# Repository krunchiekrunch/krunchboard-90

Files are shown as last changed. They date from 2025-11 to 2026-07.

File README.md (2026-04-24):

# krunchboard-90
A custom 75% (84+5+1) ANSI mechanical keyboard powered by a Raspberry Pi Pico with KMK

# About
This keyboard has 84 regular keys, 5 programmable macro keys, and 1 switch within the rotary encoder.

## Special Keys

Media Controls:

- Double tap F1: Previous media

- Double tap F2: Pause media

- Double tap F3: Next media

Rotary encoder:

- Turn: Volume Up/Down

- Press/Fn and turn: Brightness Up/Down

- Double press: Mute

[KLE](https://www.keyboard-layout-editor.com/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'&_a:6&w:2.25%3B&=Enter&=Page%20Down&_a:7%3B&=%3B&@_a:6&w:2.25%3B&=Shift&_a:4%3B&=Z&=X&=C&=V&=B&=N&=M&=%3C%0A,&=%3E%0A.&=%3F%0A%2F%2F&_a:6&w:1.75%3B&=Shift&_a:7%3B&=%E2%86%91&_a:6%3B&=End&_a:7%3B&=%3B&@_a:6&w:1.25%3B&=Ctrl&_w:1.25%3B&=Win&_w:1.25%3B&=Alt&_a:7&w:6.25%3B&=&_a:6%3B&=Alt&=Fn&=Ctrl&_a:7%3B&=%E2%86%90&=%E2%86%93&=%E2%86%92&=)

# Images

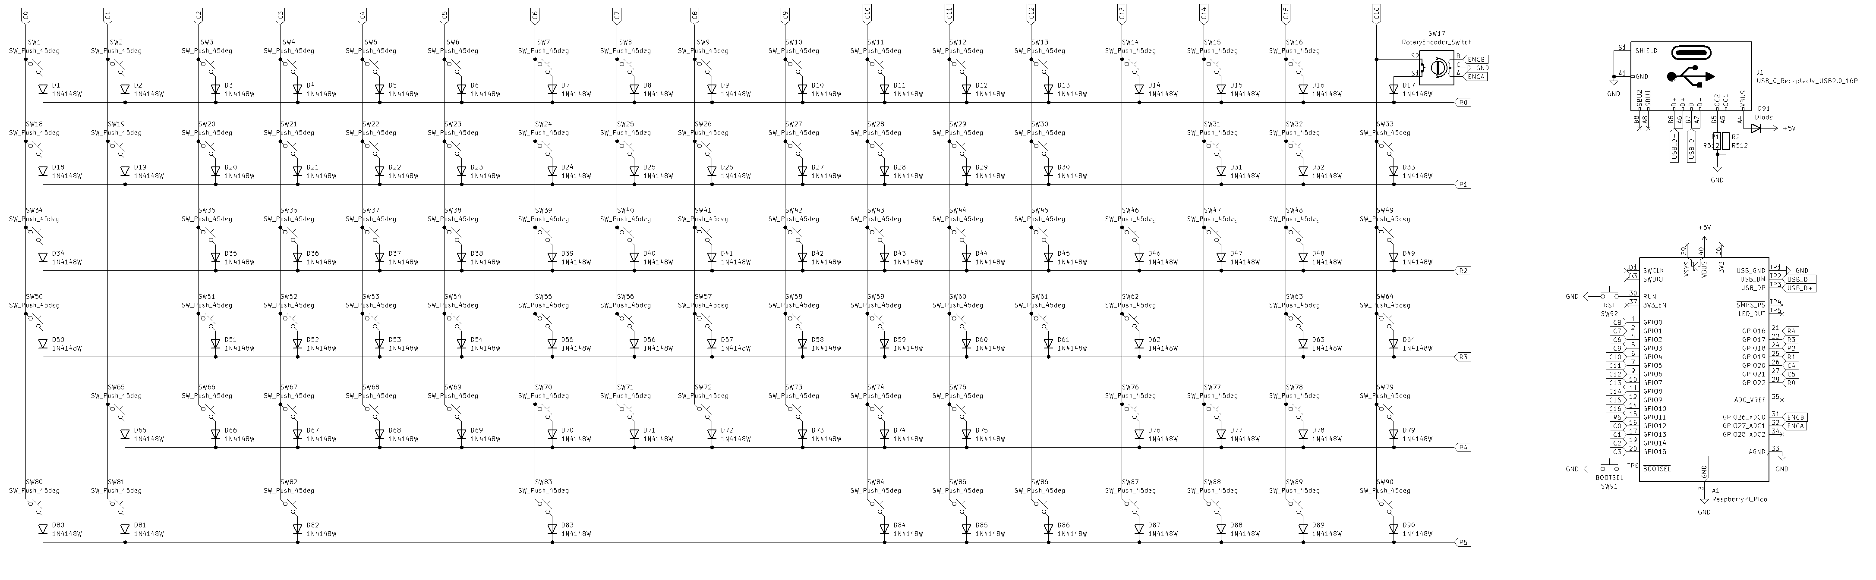
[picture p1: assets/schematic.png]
Schematic


| PCB | 3D View |
|---|---|
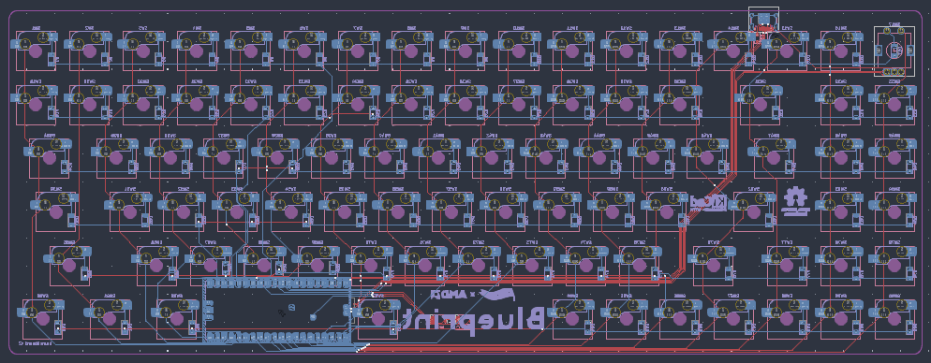
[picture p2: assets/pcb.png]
PCB
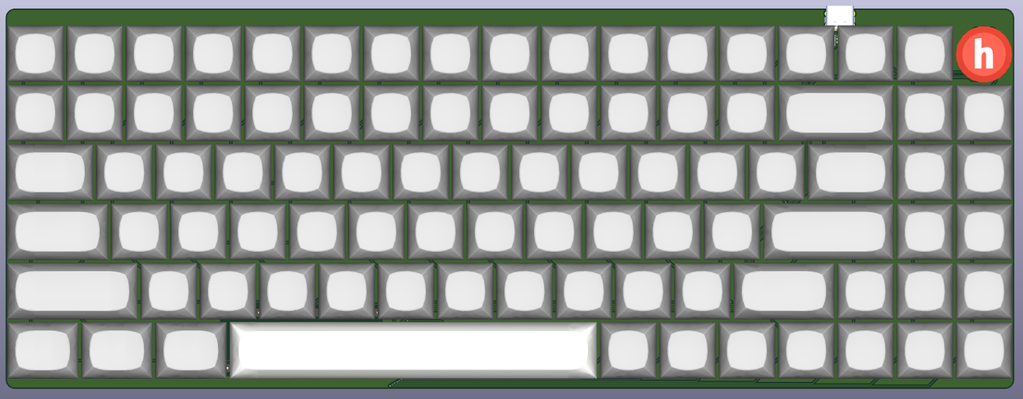
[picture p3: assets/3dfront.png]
3D-Front
|  |  |
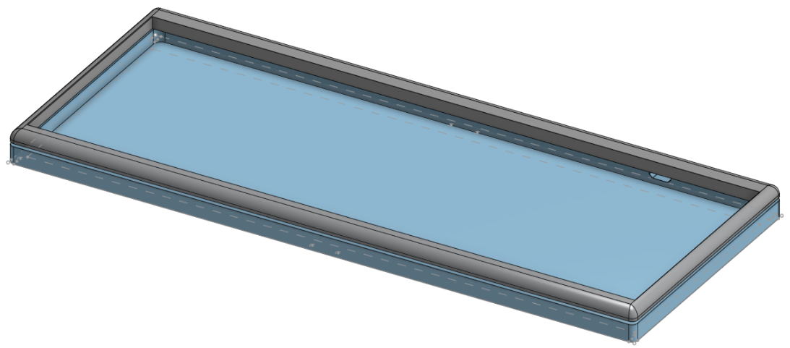
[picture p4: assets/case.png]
Case
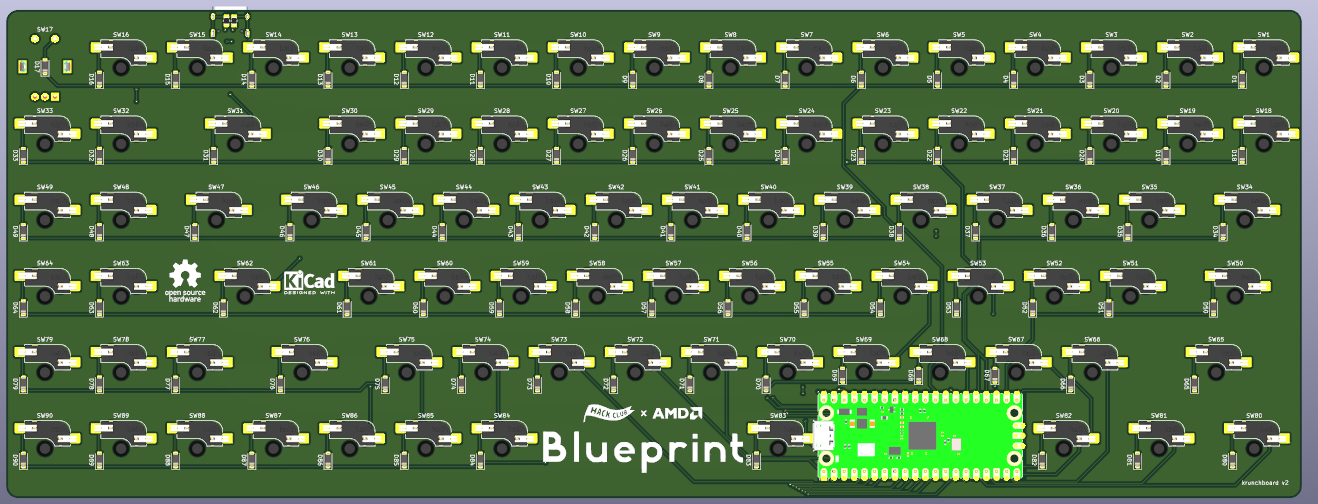
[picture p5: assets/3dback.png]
3D-Back
|  |  | 

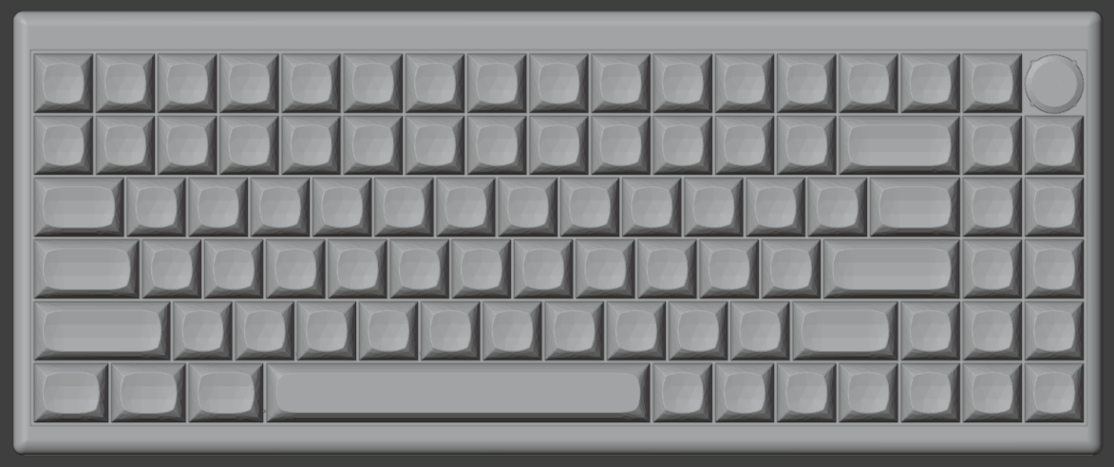
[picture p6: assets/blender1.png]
Blender


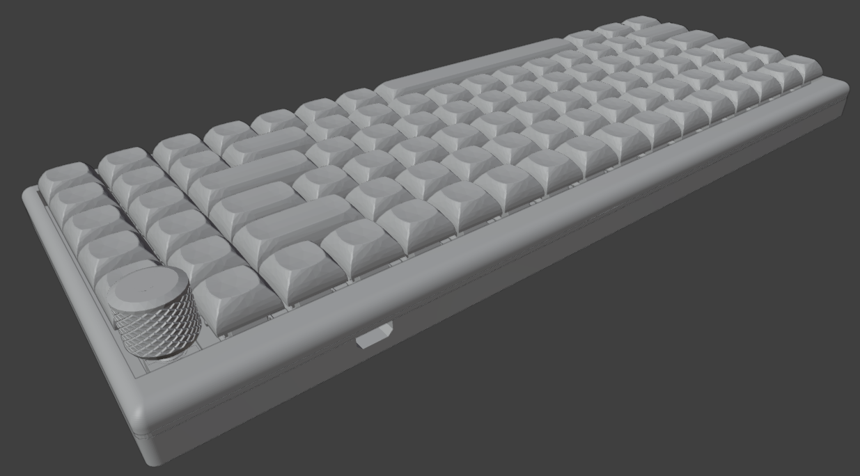
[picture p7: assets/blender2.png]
Blender






# BOM

| Qty | Item | Notes | Cost (USD) | URL |
|-----|---|---|---|-----|
| 89  | MX-Style key switches | Already have | 9.90 | [AE](https://www.aliexpress.com/item/1005002378701948.html) |
| 89  | Kailh MX hotswap socket | Already have | 8.11 | [AE](https://www.aliexpress.com/item/1005007052649640.html) |
| 90  | 1N4148W SOD-123 Diode | Already have | 2.32 | [AE](https://www.aliexpress.com/item/1005009063199018.html) |
| 1 | EC11E Rotary encoder (With switch) | Already have | 2.42 | [AE](https://www.aliexpress.com/item/1005008413622715.html) |
| 3 | MX Stabilizer (3x2u, 1x6.25u) | Already have | 2.42 | [AE](https://www.aliexpress.com/item/1005007212869086.html) |
| 1 | ANSI Keycaps set | Already have | 7.00 | [AE](https://www.aliexpress.com/item/1005007321700850.html) |
| 1 | Raspbery Pi Pico (RP2040 or RP2350) | Already have | 2.30 | [AE](https://www.aliexpress.com/item/1005006054409042.html) |
| 1 | USB-C Socket (SMD) | Already have | 1.00 | N/A |
| 2 | 5.1k/4.7k 0805 SMD resistor | Already have | 1.00 | N/A |
| 4 | M2 Screw (13.9mm max, I used 12mm) | Already have | 1.42 | [AE](https://www.aliexpress.com/item/1005003670389142.html) |
| 4 | M2 Heatset Insert (OD3.2mm, 3mm deep) | Already have | 1.73 | [AE](https://www.aliexpress.com/item/1005007640664497.html) |
| 6 | Stick-on rubber feet (Optional) | Already have | 1.18 | [AE](https://www.aliexpress.com/item/1005006832476105.html) |
| 1 | PCB | (Shipping/Tax included + $20 coupon) | 15.58 | [JLCPCB](https://jlcpcb.com) |
| 1 | 3D Printed case and plate (Blueprint only) | print-legion | 4.65 | N/A |
| | | Total: | 56.38 [20.23] | |



blueprint_logo_centered

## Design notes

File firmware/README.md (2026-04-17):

## Core Setup

* **Board:** Raspberry Pi Pico
* **Firmware:** KMK
* **Matrix:**

  * Rows: `GP22, GP19, GP18, GP17, GP16, GP11`
  * Columns: `GP12 → GP10`
* **Diode Orientation:** `COL2ROW`

## Modules

* **Macros** – custom key sequences
* **MouseKeys** – cursor + mouse control
* **MediaKeys** – volume/media shortcuts
* **EncoderHandler** – rotary encoder support
* **Layers** – multi-layer keymap
* **TapDance** – dual-function tap/hold keys

## Special Features

### Layers

* **Layer 0 (Base)** – standard keyboard layout
* **Layer 1 (Fn)** – mouse controls, system keys, macros

## Mouse Keys (Fn Layer)

  * Cursor movement
  * Left click
  * Right click
  * Scroll up/down

## Rotary Encoder

* **Default layer:**

  * Turn left → Volume Down
  * Turn right → Volume Up
* **Fn layer:**

  * Turn left → Brightness Down
  * Turn right → Brightness Up

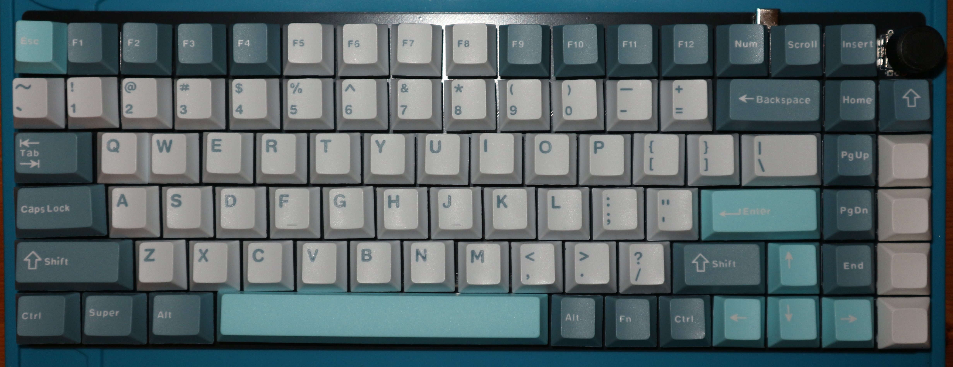
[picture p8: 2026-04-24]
assets/assm-front.JPG

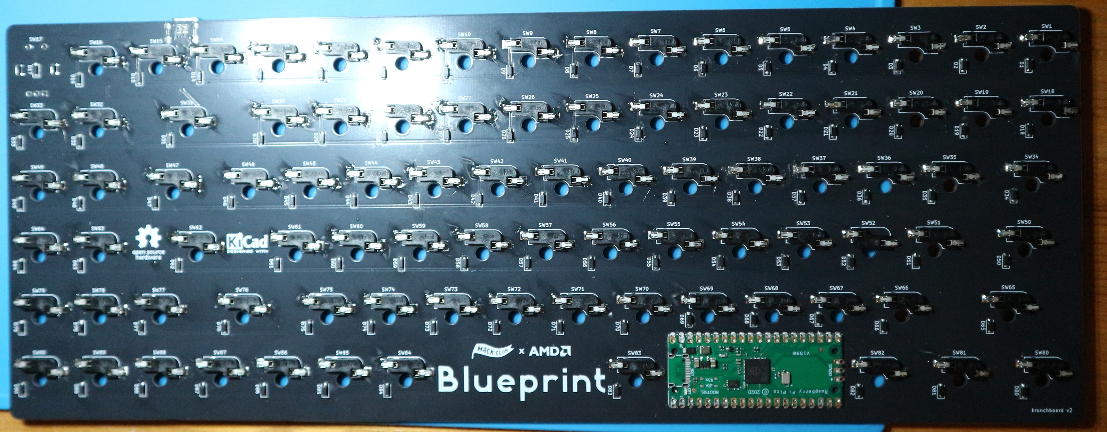
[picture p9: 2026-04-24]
assets/assm-rear.JPG

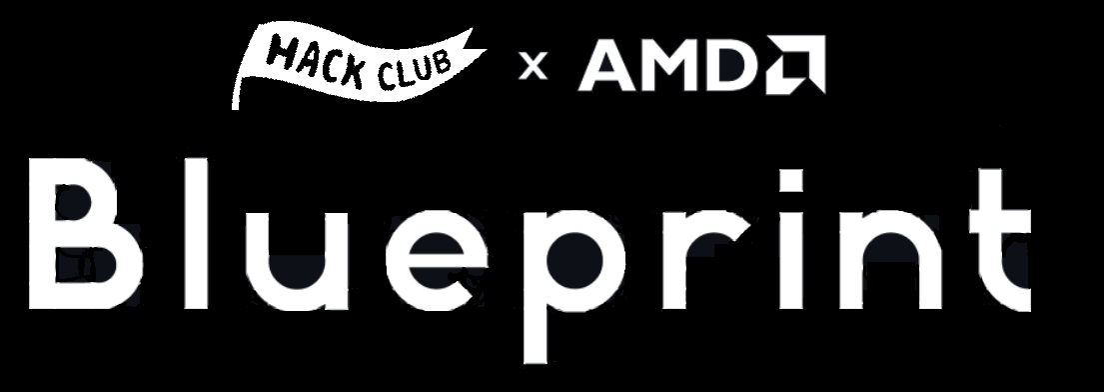
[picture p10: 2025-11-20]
assets/blueprint-monochrome.png

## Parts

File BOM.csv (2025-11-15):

Qty | Item | Notes | Cost (USD) | URL
89 | MX-Style key switches | Already have | 0.00 | N/A
89 | Kailh MX hotswap socket | Already have | 0.00 | N/A
90 | 1N4148W SOD-123 Diode | Already have | 0.00 | N/A
1 | EC11E Rotary encoder (With switch) | Already have | 0.00 | N/A
3 | 2u MX Stabilizer | Already have | 0.00 | N/A
1 | 6.25u MX Stabilizer | Already have | 0.00 | N/A
1 | Keycaps set | Already have | 0.00 | N/A
1 | Raspbery Pi Pico (RP2040 or RP2350) | Already have | 0.00 | N/A
1 | USB-C Socket (SMD) | Already have | 0.00 | N/A
2 | 5.1k 0402 SMD resistor | Already have | 0.00 | N/A
4 | M2 Screw (13.9mm max) | Already have | 0.00 | N/A
4 | M2 Heatset Insert (OD3.2mm, 3mm deep) | Already have | 0.00 | N/A
6 | Stick-on rubber feet (Optional) | Already have | 0.00 | N/A
1 | PCB | (Shipping included + $20 coupon) | 12.01 | https://jlcpcb.com
1 | 3D Printed case and plate | print-legion | 4.60 | N/A
 | Total |  | 16.61

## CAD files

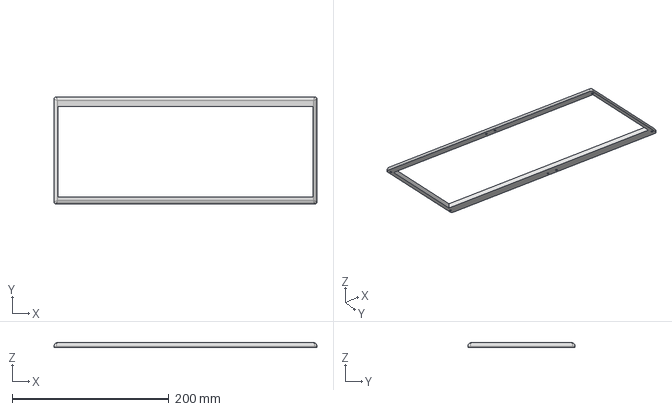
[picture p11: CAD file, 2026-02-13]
case-cad/krunchboard-90-castop.step
335.1 x 136.5 x 6.30 mm

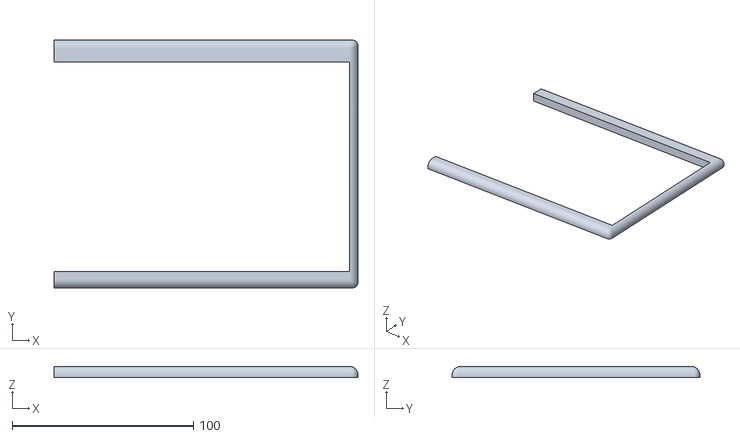
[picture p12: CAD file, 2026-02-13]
production/case-half/krunchboard-90-castop-right.stl
167.5 x 136.5 x 6.30

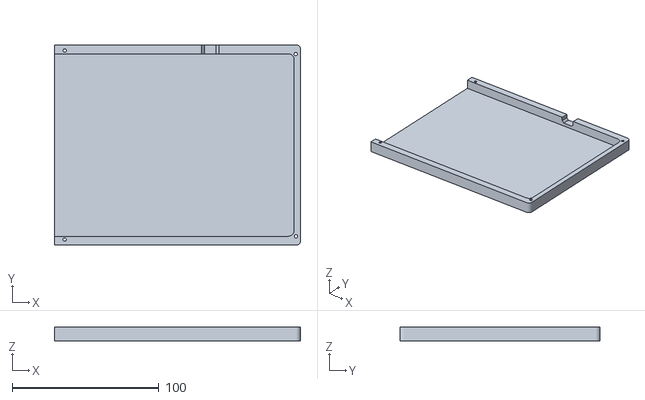
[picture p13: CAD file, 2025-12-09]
production/case-half/krunchboard-90-casebottom-right.stl
167.5 x 136.5 x 9.30

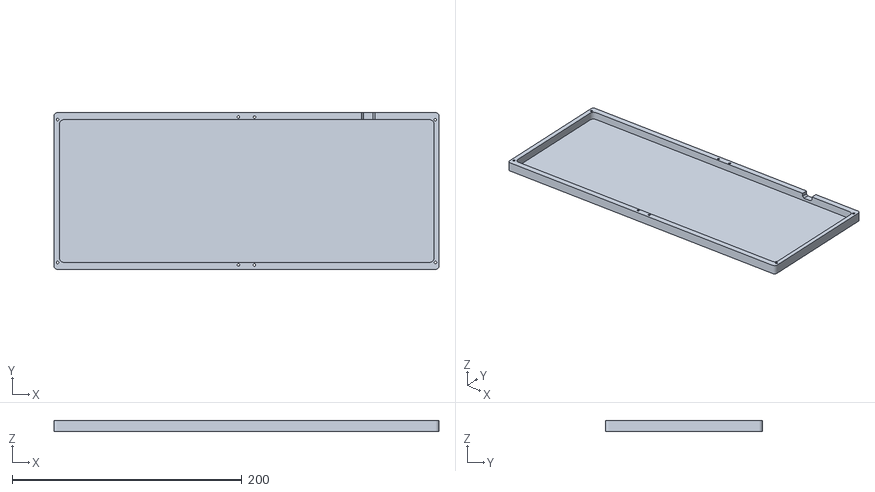
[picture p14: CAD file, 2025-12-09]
production/krunchboard-90-casebottom.stl
335.1 x 136.5 x 9.30

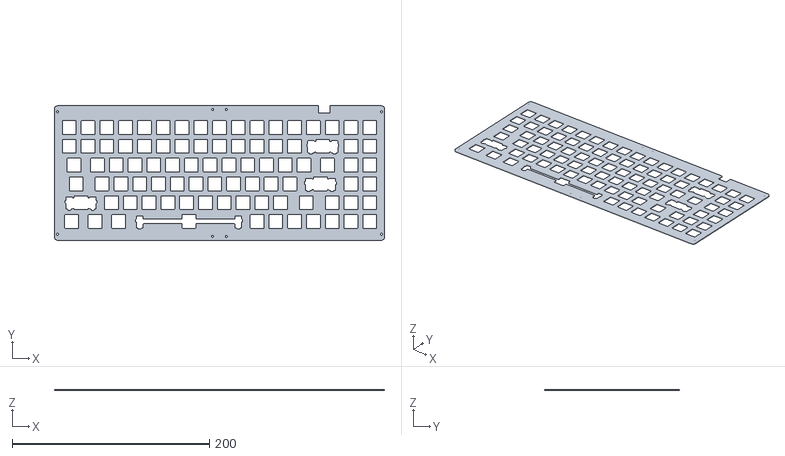
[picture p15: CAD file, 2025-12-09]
production/krunchboard-90-plate.stl
334.8 x 136.5 x 1.51

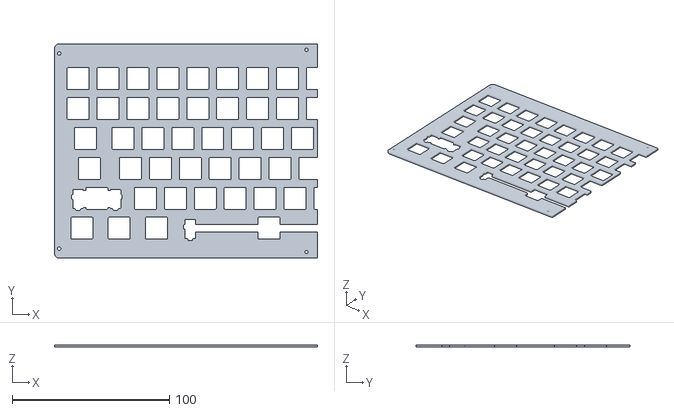
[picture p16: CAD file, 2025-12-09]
production/case-half/krunchboard-90-plate-left.stl
167.4 x 136.5 x 1.51

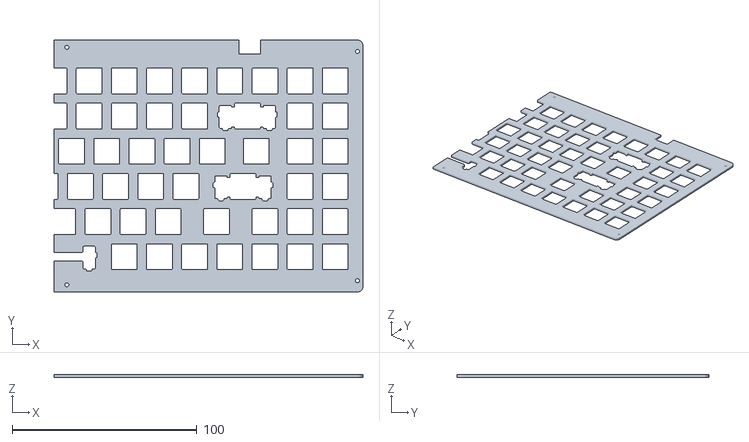
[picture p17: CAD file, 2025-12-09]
production/case-half/krunchboard-90-plate-right.stl
167.4 x 136.5 x 1.51

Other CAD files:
production/krunchboard-90-castop.stl
case-cad/krunchboard-90-casetop.step
case-cad/krunchboard-90-casebottom.step
production/case-half/krunchboard-90-casetop-left.stl
production/case-half/krunchboard-90-casebottom-left.stl
case-cad/krunchboard90-casebottom.step
case-cad/krunchboard90-casetop.step

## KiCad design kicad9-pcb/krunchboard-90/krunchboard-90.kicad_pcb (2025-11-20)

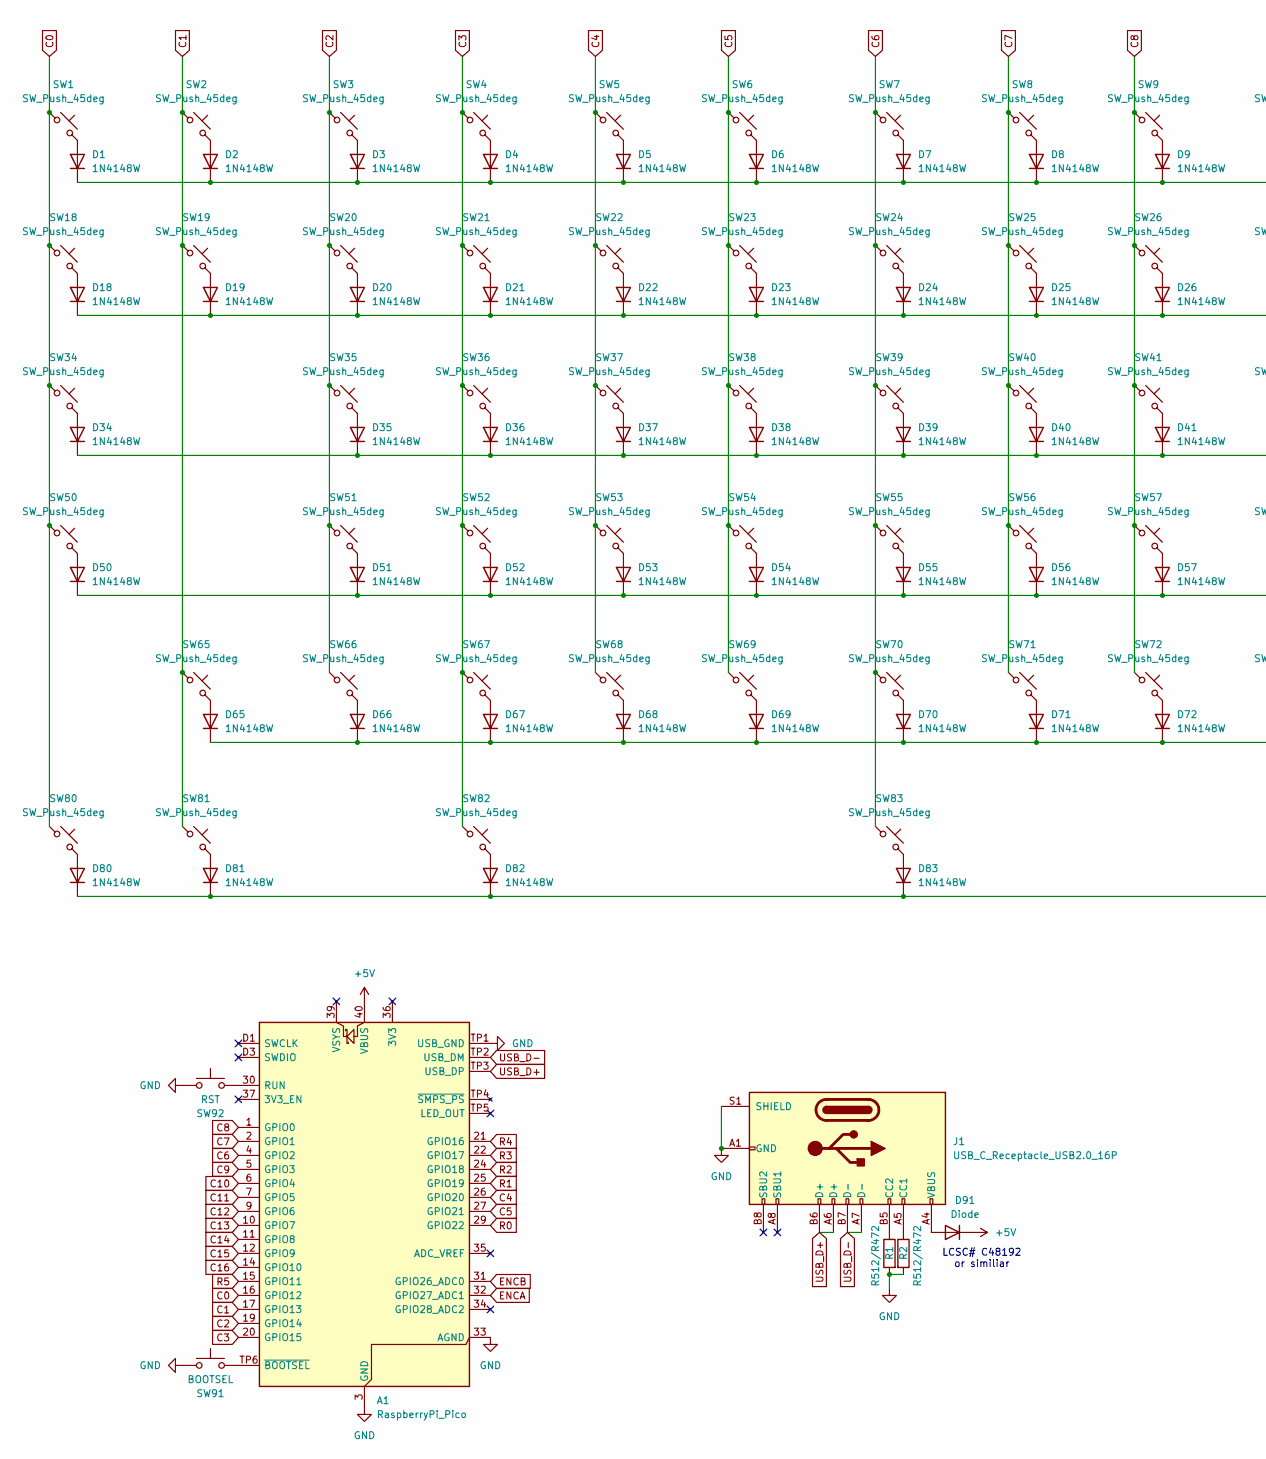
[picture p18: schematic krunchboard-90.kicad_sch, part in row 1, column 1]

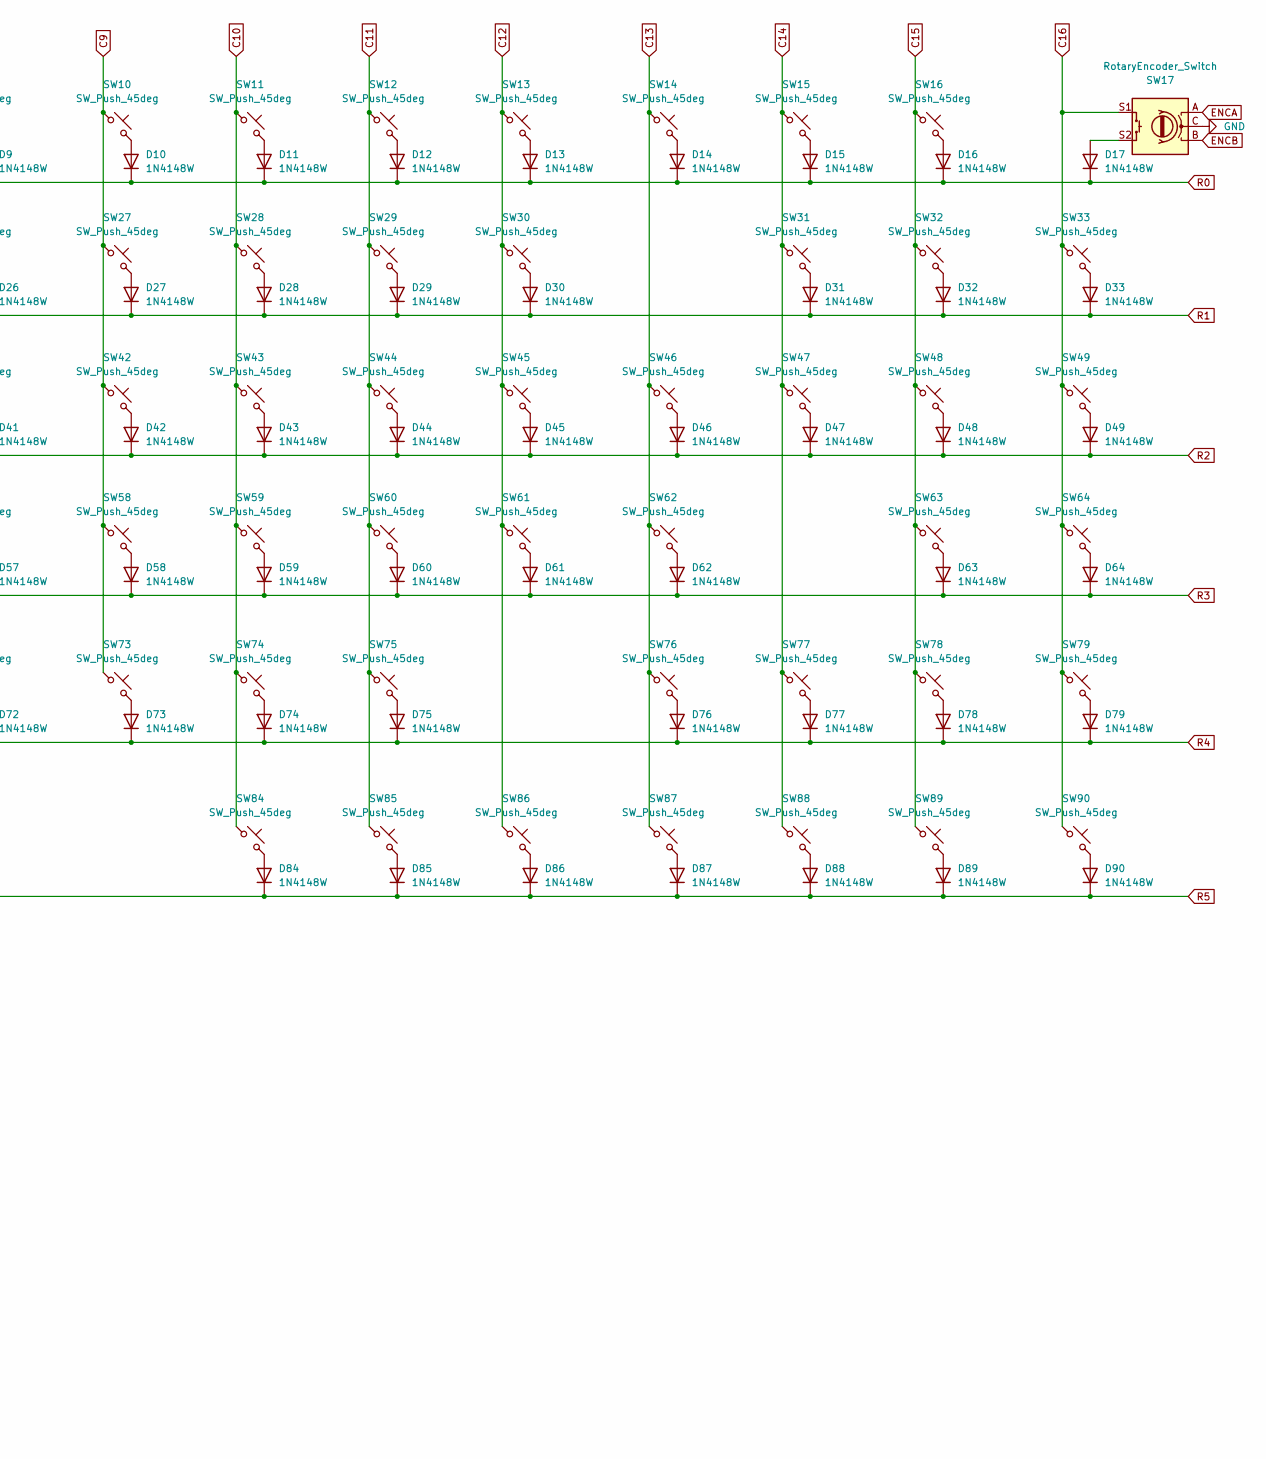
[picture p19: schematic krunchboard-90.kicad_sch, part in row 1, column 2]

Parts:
A1: RaspberryPi_Pico; RaspberryPi_Pico_SMD
D1, D2, D3, D4, D5, D6, D7, D8, D9, D10, D11, D12, D13, D14, D15, D16, D17, D18, D19, D20, D21, D22, D23, D24, D25, D26, D27, D28, D29, D30, D31, D32, D33, D34, D35, D36, D37, D38, D39, D40, D41, D42, D43, D44, D45, D46, D47, D48, D49, D50, D51, D52, D53, D54, D55, D56, D57, D58, D59, D60, D61, D62, D63, D64, D65, D66, D67, D68, D69, D70, D71, D72, D73, D74, D75, D76, D77, D78, D79, D80, D81, D82, D83, D84, D85, D86, D87, D88, D89, D90: 1N4148W; D_SOD-123
D91: Diode; D_SOD-323_HandSoldering
J1: USB_C_Receptacle_USB2.0_16P; USB_C_Receptacle_HCTL_HC-TYPE-C-16P-01A
R1, R2: R512/R472; R_0805_2012Metric_Pad1.20x1.40mm_HandSolder
SW1, SW2, SW3, SW4, SW5, SW6, SW7, SW8, SW9, SW10, SW11, SW12, SW13, SW14, SW15, SW16, SW18, SW19, SW20, SW21, SW22, SW23, SW24, SW25, SW26, SW27, SW28, SW29, SW30, SW31, SW32, SW33, SW34, SW35, SW36, SW37, SW38, SW39, SW40, SW41, SW42, SW43, SW44, SW45, SW46, SW47, SW48, SW49, SW50, SW51, SW52, SW53, SW54, SW55, SW56, SW57, SW58, SW59, SW60, SW61, SW62, SW63, SW64, SW65, SW66, SW67, SW68, SW69, SW70, SW71, SW72, SW73, SW74, SW75, SW76, SW77, SW78, SW79, SW80, SW81, SW82, SW83, SW84, SW85, SW86, SW87, SW88, SW89, SW90: SW_Push_45deg; Kailh_socket_MX_platemount_plated
SW17: RotaryEncoder_Switch; RotaryEncoder_Alps_EC11E-Switch_Vertical_H20mm
SW91: BOOTSEL; SW_SPST_TS-1088-xR025
SW92: RST; SW_SPST_TS-1088-xR025

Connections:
+5V: A1.40 (VBUS), D91.1 (K)
C0: A1.16 (GPIO12), SW1.1, SW18.1, SW34.1, SW50.1, SW80.1
C1: A1.17 (GPIO13), SW2.1, SW19.1, SW65.1, SW81.1
C2: A1.19 (GPIO14), SW3.1, SW20.1, SW35.1, SW51.1, SW66.1
C3: A1.20 (GPIO15), SW4.1, SW21.1, SW36.1, SW52.1, SW67.1, SW82.1
C4: A1.26 (GPIO20), SW5.1, SW22.1, SW37.1, SW53.1, SW68.1
C5: A1.27 (GPIO21), SW6.1, SW23.1, SW38.1, SW54.1, SW69.1
C6: A1.4 (GPIO2), SW7.1, SW24.1, SW39.1, SW55.1, SW70.1, SW83.1
C7: A1.2 (GPIO1), SW8.1, SW25.1, SW40.1, SW56.1, SW71.1
C8: A1.1 (GPIO0), SW9.1, SW26.1, SW41.1, SW57.1, SW72.1
C9: A1.5 (GPIO3), SW10.1, SW27.1, SW42.1, SW58.1, SW73.1
C10: A1.6 (GPIO4), SW11.1, SW28.1, SW43.1, SW59.1, SW74.1, SW84.1
C11: A1.7 (GPIO5), SW12.1, SW29.1, SW44.1, SW60.1, SW75.1, SW85.1
C12: A1.9 (GPIO6), SW13.1, SW30.1, SW45.1, SW61.1, SW86.1
C13: A1.10 (GPIO7), SW14.1, SW46.1, SW62.1, SW76.1, SW87.1
C14: A1.11 (GPIO8), SW15.1, SW31.1, SW47.1, SW77.1, SW88.1
C15: A1.12 (GPIO9), SW16.1, SW32.1, SW48.1, SW63.1, SW78.1, SW89.1
C16: A1.14 (GPIO10), SW17.S1, SW33.1, SW49.1, SW64.1, SW79.1, SW90.1
ENCA: A1.32 (GPIO27_ADC1), SW17.A
ENCB: A1.31 (GPIO26_ADC0), SW17.B
GND: A1.3 (GND), A1.8 (GND), A1.13 (GND), A1.18 (GND), A1.23 (GND), A1.28 (GND), A1.33 (AGND), A1.38 (GND), A1.D2 (GND), A1.TP1 (USB_GND), J1.A1 (GND), J1.A12 (GND), J1.B1 (GND), J1.B12 (GND), J1.S1 (SHIELD), R1.2, R2.2, SW17.C, SW91.1, SW92.1
unnamed: A1.30 (RUN), SW92.2
unnamed: A1.TP6 (~BOOTSEL), SW91.2
unnamed: D1.2 (A), SW1.2
unnamed: D2.2 (A), SW2.2
unnamed: D3.2 (A), SW3.2
unnamed: D4.2 (A), SW4.2
unnamed: D5.2 (A), SW5.2
unnamed: D6.2 (A), SW6.2
unnamed: D7.2 (A), SW7.2
unnamed: D8.2 (A), SW8.2
unnamed: D9.2 (A), SW9.2
unnamed: D10.2 (A), SW10.2
unnamed: D11.2 (A), SW11.2
unnamed: D12.2 (A), SW12.2
unnamed: D13.2 (A), SW13.2
unnamed: D14.2 (A), SW14.2
unnamed: D15.2 (A), SW15.2
unnamed: D16.2 (A), SW16.2
unnamed: D17.2 (A), SW17.S2
unnamed: D18.2 (A), SW18.2
unnamed: D19.2 (A), SW19.2
unnamed: D20.2 (A), SW20.2
unnamed: D21.2 (A), SW21.2
unnamed: D22.2 (A), SW22.2
unnamed: D23.2 (A), SW23.2
unnamed: D24.2 (A), SW24.2
unnamed: D25.2 (A), SW25.2
unnamed: D26.2 (A), SW26.2
unnamed: D27.2 (A), SW27.2
unnamed: D28.2 (A), SW28.2
unnamed: D29.2 (A), SW29.2
unnamed: D30.2 (A), SW30.2
unnamed: D31.2 (A), SW31.2
unnamed: D32.2 (A), SW32.2
unnamed: D33.2 (A), SW33.2
unnamed: D34.2 (A), SW34.2
unnamed: D35.2 (A), SW35.2
unnamed: D36.2 (A), SW36.2
unnamed: D37.2 (A), SW37.2
unnamed: D38.2 (A), SW38.2
unnamed: D39.2 (A), SW39.2
unnamed: D40.2 (A), SW40.2
unnamed: D41.2 (A), SW41.2
unnamed: D42.2 (A), SW42.2
unnamed: D43.2 (A), SW43.2
unnamed: D44.2 (A), SW44.2
unnamed: D45.2 (A), SW45.2
unnamed: D46.2 (A), SW46.2
unnamed: D47.2 (A), SW47.2
unnamed: D48.2 (A), SW48.2
unnamed: D49.2 (A), SW49.2
unnamed: D50.2 (A), SW50.2
unnamed: D51.2 (A), SW51.2
unnamed: D52.2 (A), SW52.2
unnamed: D53.2 (A), SW53.2
unnamed: D54.2 (A), SW54.2
unnamed: D55.2 (A), SW55.2
unnamed: D56.2 (A), SW56.2
unnamed: D57.2 (A), SW57.2
unnamed: D58.2 (A), SW58.2
unnamed: D59.2 (A), SW59.2
unnamed: D60.2 (A), SW60.2
unnamed: D61.2 (A), SW61.2
unnamed: D62.2 (A), SW62.2
unnamed: D63.2 (A), SW63.2
unnamed: D64.2 (A), SW64.2
unnamed: D65.2 (A), SW65.2
unnamed: D66.2 (A), SW66.2
unnamed: D67.2 (A), SW67.2
unnamed: D68.2 (A), SW68.2
unnamed: D69.2 (A), SW69.2
unnamed: D70.2 (A), SW70.2
unnamed: D71.2 (A), SW71.2
unnamed: D72.2 (A), SW72.2
unnamed: D73.2 (A), SW73.2
unnamed: D74.2 (A), SW74.2
unnamed: D75.2 (A), SW75.2
unnamed: D76.2 (A), SW76.2
unnamed: D77.2 (A), SW77.2
unnamed: D78.2 (A), SW78.2
unnamed: D79.2 (A), SW79.2
unnamed: D80.2 (A), SW80.2
unnamed: D81.2 (A), SW81.2
unnamed: D82.2 (A), SW82.2
unnamed: D83.2 (A), SW83.2
unnamed: D84.2 (A), SW84.2
unnamed: D85.2 (A), SW85.2
unnamed: D86.2 (A), SW86.2
unnamed: D87.2 (A), SW87.2
unnamed: D88.2 (A), SW88.2
unnamed: D89.2 (A), SW89.2
unnamed: D90.2 (A), SW90.2
unnamed: D91.2 (A), J1.A4 (VBUS), J1.A9 (VBUS), J1.B4 (VBUS), J1.B9 (VBUS)
unnamed: J1.A5 (CC1), R2.1
unnamed: J1.B5 (CC2), R1.1
R0: A1.29 (GPIO22), D1.1 (K), D2.1 (K), D3.1 (K), D4.1 (K), D5.1 (K), D6.1 (K), D7.1 (K), D8.1 (K), D9.1 (K), D10.1 (K), D11.1 (K), D12.1 (K), D13.1 (K), D14.1 (K), D15.1 (K), D16.1 (K), D17.1 (K)
R1: A1.25 (GPIO19), D18.1 (K), D19.1 (K), D20.1 (K), D21.1 (K), D22.1 (K), D23.1 (K), D24.1 (K), D25.1 (K), D26.1 (K), D27.1 (K), D28.1 (K), D29.1 (K), D30.1 (K), D31.1 (K), D32.1 (K), D33.1 (K)
R2: A1.24 (GPIO18), D34.1 (K), D35.1 (K), D36.1 (K), D37.1 (K), D38.1 (K), D39.1 (K), D40.1 (K), D41.1 (K), D42.1 (K), D43.1 (K), D44.1 (K), D45.1 (K), D46.1 (K), D47.1 (K), D48.1 (K), D49.1 (K)
R3: A1.22 (GPIO17), D50.1 (K), D51.1 (K), D52.1 (K), D53.1 (K), D54.1 (K), D55.1 (K), D56.1 (K), D57.1 (K), D58.1 (K), D59.1 (K), D60.1 (K), D61.1 (K), D62.1 (K), D63.1 (K), D64.1 (K)
R4: A1.21 (GPIO16), D65.1 (K), D66.1 (K), D67.1 (K), D68.1 (K), D69.1 (K), D70.1 (K), D71.1 (K), D72.1 (K), D73.1 (K), D74.1 (K), D75.1 (K), D76.1 (K), D77.1 (K), D78.1 (K), D79.1 (K)
R5: A1.15 (GPIO11), D80.1 (K), D81.1 (K), D82.1 (K), D83.1 (K), D84.1 (K), D85.1 (K), D86.1 (K), D87.1 (K), D88.1 (K), D89.1 (K), D90.1 (K)
USB_D+: A1.TP3 (USB_DP), J1.A6 (D+), J1.B6 (D+)
USB_D-: A1.TP2 (USB_DM), J1.A7 (D-), J1.B7 (D-)

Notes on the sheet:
LCSC# C48192 or similiar

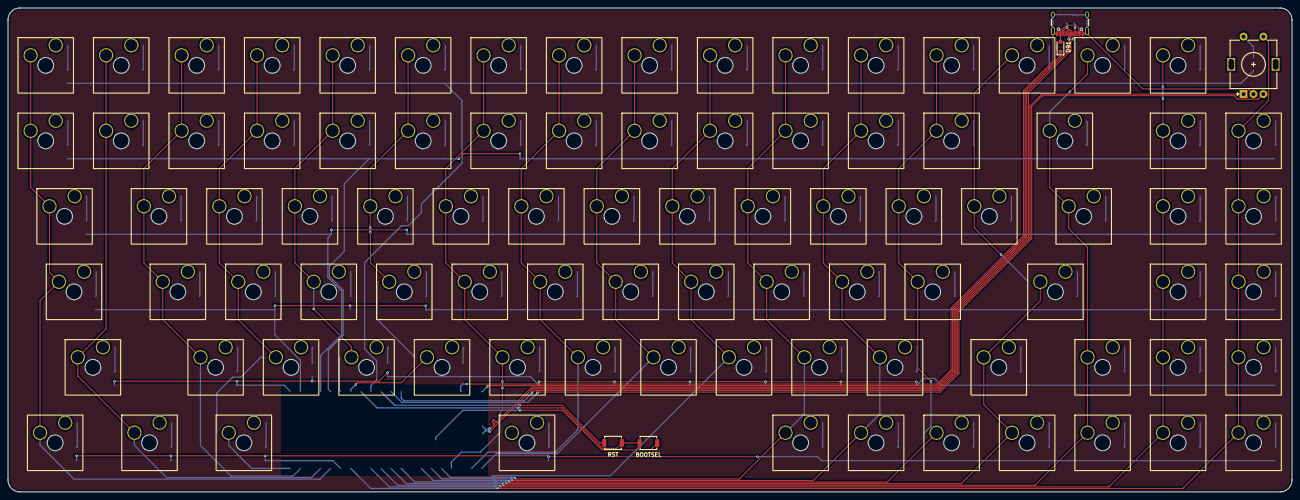
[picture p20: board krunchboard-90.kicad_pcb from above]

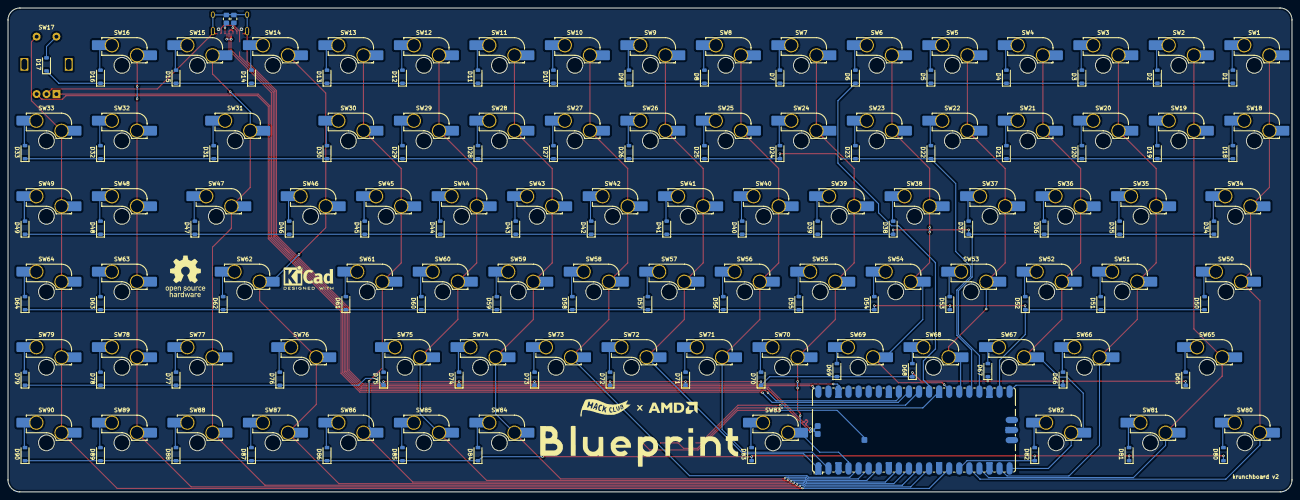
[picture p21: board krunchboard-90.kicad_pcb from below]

Board: 2 copper layers, 324.0 x 122.1 mm, 188 parts (94 on the bottom side), 124 nets.

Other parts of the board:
logo1: KiCad-Logo2_5mm_SilkScreen

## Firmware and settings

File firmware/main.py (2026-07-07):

custom = "custom text" 

import board
# import digitalio
from kmk.kmk_keyboard import KMKKeyboard
from kmk.scanners.keypad import MatrixScanner
from kmk.keys import KC
from kmk.scanners import DiodeOrientation
from kmk.extensions.RGB import RGB, AnimationModes
from kmk.modules.macros import Macros, Press, Release, Tap, Delay
from kmk.modules.mouse_keys import MouseKeys
from kmk.extensions.media_keys import MediaKeys
from kmk.modules.encoder import EncoderHandler
from kmk.modules.layers import Layers
from kmk.modules.tapdance import TapDance

keyboard = KMKKeyboard()
macros = Macros()
keyboard.modules.append(macros)
encoder_handler = EncoderHandler()
tapdance = TapDance()
tapdance.tap_time = 250
mousekeys = MouseKeys(acc_interval = 10)
keyboard.modules.append(mousekeys)
keyboard.extensions.append(MediaKeys())
keyboard.modules.append(encoder_handler)
keyboard.modules.append(Layers())
keyboard.modules.append(tapdance)

# R0 - R5
keyboard.row_pins = (board.GP22, board.GP19, board.GP18, board.GP17, board.GP16, board.GP11)
# C0 - C16
keyboard.col_pins = (board.GP12, board.GP13, board.GP14, board.GP15, board.GP20, board.GP21, board.GP2, board.GP1, board.GP0, board.GP3, board.GP4, board.GP5, board.GP6, board.GP7, board.GP8, board.GP9, board.GP10)

keyboard.diode_orientation = DiodeOrientation.COL2ROW

_______ = KC.TRNS
xxxxxxx = KC.NO
xxxx = KC.NO
Fn = KC.MO(1)

F1 = KC.TD(KC.F1, KC.MPRV)
F2 = KC.TD(KC.F2, KC.MPLY)
F3 = KC.TD(KC.F3, KC.MNXT)

RSW = KC.TD(Fn, KC.MUTE)
LOCK = KC.MACRO(Press(KC.LGUI), Delay(100), Tap(KC.L), Release(KC.LGUI))
text = KC.TD(KC.NO, KC.MACRO(custom, Tap(KC.ENTER)))

WAVE = KC.MACRO(Tap(KC.DOT), Delay(100), Tap(KC.N1))
GD = KC.MACRO(Tap(KC.E), Tap(KC.T), Tap(KC.Q), Tap(KC.Y), Tap(KC.R))
WAVEGD = KC.TD(WAVE, GD)

FPS = KC.MACRO(Press(KC.LSFT), Delay(100), Tap(KC.F5), Release(KC.LSFT))
PING = KC.MACRO(Press(KC.LCTRL), Press(KC.LSFT), Press(KC.F7), Release(KC.LCTRL), Release(KC.LSFT), Release(KC.F7))
FPSPING = KC.TD(FPS, PING)

keyboard.keymap = [
    # Base (Layer 0)
    [
        KC.ESC,   F1,      F2,    F3,      KC.F4, KC.F5, KC.F6,    KC.F7, KC.F8, KC.F9,    KC.F10,  KC.F11,    KC.F12,   KC.PSCR,  KC.PAUS, KC.DEL,   RSW,
        KC.GRAVE, KC.N1,   KC.N2, KC.N3,   KC.N4, KC.N5, KC.N6,    KC.N7, KC.N8, KC.N9,    KC.N0,   KC.MINUS,  KC.EQUAL, xxxxxxx,  KC.BSPC, KC.HOME,  KC.MUTE,
        KC.TAB,   xxxxxxx, KC.Q,  KC.W,    KC.E,  KC.R,  KC.T,     KC.Y,  KC.U,  KC.I,     KC.O,    KC.P,      KC.LBRC,  KC.RBRC,  KC.BSLS, KC.PGUP,  xxxxxxx,
        KC.CAPS,  xxxxxxx, KC.A,  KC.S,    KC.D,  KC.F,  KC.G,     KC.H,  KC.J,  KC.K,     KC.L,    KC.SCOLON, KC.QUOTE, KC.ENTER, xxxxxxx, KC.PGDN,  WAVEGD,
        xxxxxxx,  KC.LSFT, KC.Z,  KC.X,    KC.C,  KC.V,  KC.B,     KC.N,  KC.M,  KC.COMMA, KC.DOT,  KC.SLASH,  xxxxxxx,  KC.RSFT,  KC.UP,   KC.END,   FPSPING,
        KC.LCTRL, KC.LGUI, xxxx,  KC.LALT, xxxx,  xxxx,  KC.SPACE, xxxx,  xxxx,  xxxxxxx,  KC.RALT, Fn,        KC.RCTRL, KC.LEFT,  KC.DOWN, KC.RIGHT, xxxxxxx,
    ],
    # Fn (Layer 1)
    [
        xxxxxxx,  KC.F13,  KC.F14,  KC.F15,   KC.F16,   KC.F17,   KC.F18,    KC.F19,   KC.F20,  KC.F21,  KC.F22,  KC.F23,   KC.F24,  KC.NLCK, KC.SLCK, KC.INS,  _______,
        KC.RESET, _______, _______,  _______,  _______,  _______,   _______,  _______, _______, _______, _______,  _______, _______, _______, _______, _______, _______,
        _______,  _______, _______,  KC.MS_UP, _______,  KC.MB_LMB, KC.MW_UP, _______, _______, _______, _______,  _______, _______, _______, _______, _______, _______,
        _______,  _______, KC.MS_LT, KC.MS_DN, KC.MS_RT, KC.MB_RMB, KC.MW_DN, _______, _______, _______, LOCK,     _______, _______, _______, _______, _______, text,
        _______,  _______, _______,  _______,  _______,  _______,   _______,  _______, _______, _______, _______,  _______, _______, _______, _______, _______, _______,
        _______,  _______, _______,  _______,  _______,  _______,   _______,  _______, _______, _______, _______,  _______, _______, _______, _______, _______, xxxxxxx,
    ]
]

# volume knob
encoder_handler.pins = ((board.GP26, board.GP27),)
encoder_handler.map = [
    ((KC.VOLD, KC.VOLU),), # Volume
    ((KC.BRID, KC.BRIU),), # Brightness (Fn)
    ]

# Pico GP25 LED
'''
led = digitalio.DigitalInOut(board.GP25)
led.direction = digitalio.Direction.OUTPUT
led.value = True
'''

if __name__ == '__main__':
    keyboard.go()

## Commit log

2025-11-13 case files, images, pcb
    [case-bottom.step, case-bottom.stl, case-top.step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]
2025-11-14 updated readme about, formatting, bom info
2025-11-15 added coupon to bom
    [BOM.csv]
2025-11-15 fixed bom.csv formatting
    [BOM.csv]
2025-11-15 updated pcb traces, firmware
    [krunchboard-90.kicad_pcb]
2025-11-20 updated case,plate (added 4 extra mounting hole in center), updated pcb to prod v1
    [HALF_krunchboard90-casebottomL.stl, HALF_krunchboard90-casebottomR.stl, HALF_krunchboard90-casetop.stl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]
2025-11-21 Integrate GPIO LED control using digitalio, added missing layer import
    Added support for controlling a GPIO LED on GP25.
    [main.py]
2025-11-21 updated resistor package size in bom
2025-12-09 bom update
2025-12-09 commented out unnecessary power saving code
2025-12-09 added a screw reference chart
2025-12-09 made screw passthrough hole bigger, fixed usb-c clearance
    [HALF_krunchboard90-casebottomL.stl, HALF_krunchboard90-casebottomR.stl, HALF_krunchboard90-casetop.stl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]
2026-01-19 mouse control and reset/reload
    [main.py]
2026-02-13 updated top of the case to hopefully fit without having to adjust heatset insert distance
    [krunchboard-90-casetop-right.stl, krunchboard-90-casetop.stl, krunchboard-90-castop-right.stl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]
2026-04-17 code documentation / renamed pcb folder
    [krunchboard-90-plate.kicad_pcb, krunchboard-90-plate.kicad_sch, krunchboard-90.kicad_pcb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]
